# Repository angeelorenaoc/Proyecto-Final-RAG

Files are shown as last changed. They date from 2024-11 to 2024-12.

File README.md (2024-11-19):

# Proyecto-Final-RAG
Este proyecto tiene como objetivo desarrollar un robot guía autónomo para el pasillo del bloque 18 de la universidad. Diseñado para mejorar la experiencia de los estudiantes nuevos y visitantes, el robot proporcionará información útil y rutas. Él estará equipado con una pantalla OLED y un teclado, facilitando la interacción con los usuarios.

### Diagrama de Bloques: Estructura de Hardware

WhatsApp Image 2024-11-12 at 9 45 18 PM

### Materiales 
  *  Pantalla OLED.
  *  Balizas: Antenas XBEE PRO.
  *  Raspberry Pi pico

### Diagrama de Flujo: Estructura del Código
WhatsApp Image 2024-11-04 at 5 30 25 AM

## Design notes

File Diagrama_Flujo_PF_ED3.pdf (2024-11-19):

Diagrama de máquinas de estado del Programa Principal

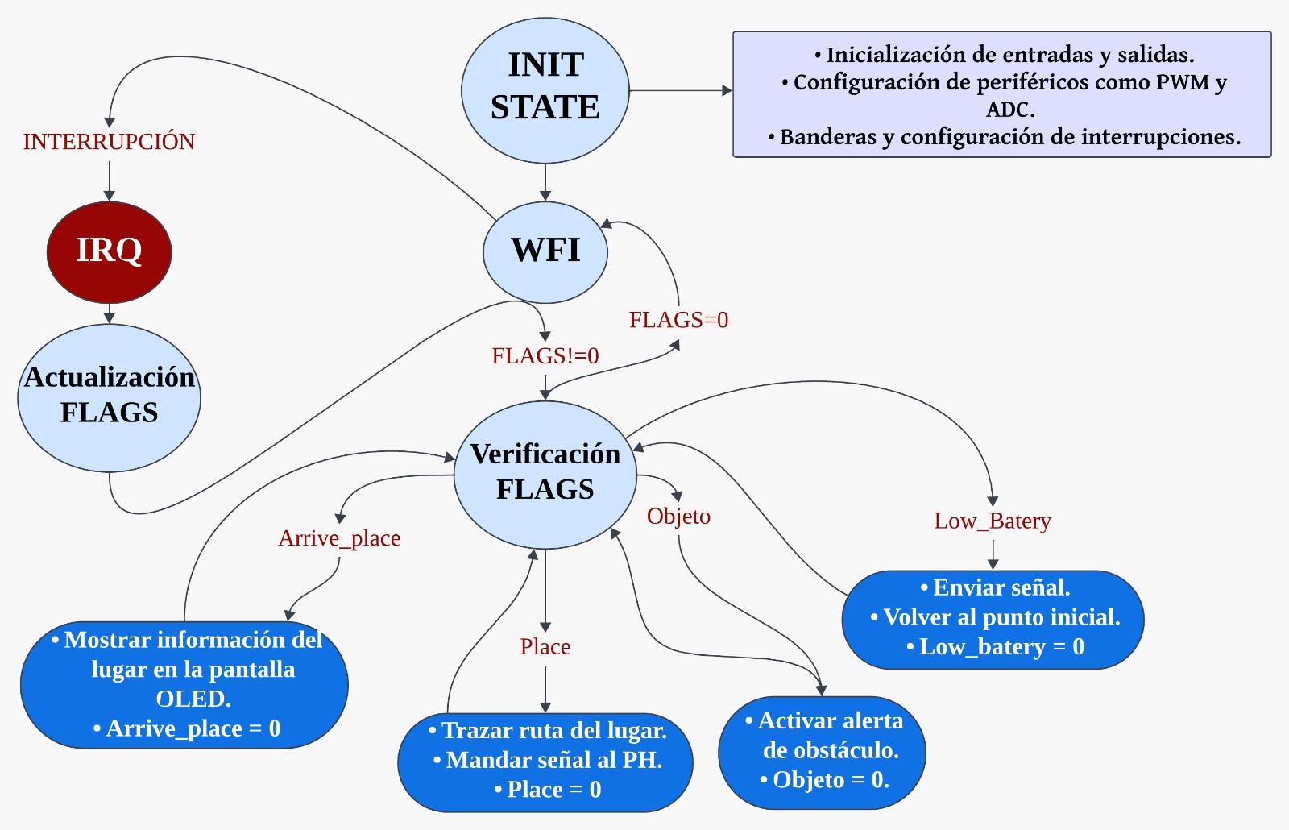
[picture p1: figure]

En primera instancia se optó por un flujo de tipo Polling + Interrup Driven ya que nos permite tener un buen control de los eventos sin necesidad de estar en un estado de constante atención por parte del procesador lo que ayuda también al consumo energético de sistema; El programa parte por la inicialización de todas las variables y GPIOs necesarios como también de los distintos periféricos (PWM, ADC, UART, I2C) para interconectar el MCU con el mundo exterior. Seguidamente activa todas las interrupciones requeridas que modificaran las respectivas flags dependiendo del evento que se les asigne, algunas generadas por medio de alarmas o PITs , o por interrupciones procedentes de los botones conectados.
Ya entrando en el bucle principal la CPU esperara a la ocurrencia de algún evento que modifique las flags y estas a su vez indiquen que procedimiento realizar:
- Refresco de la pantalla OLED a través de la interfaz I2C
- Generación del PWM para el movimiento
- Detección de obstáculos.
- Actualización de la posición relativa, esto incluye la lectura del nivel de potencia de cada una de las balizas
- Lectura del nivel de batería actual

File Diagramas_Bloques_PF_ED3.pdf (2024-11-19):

Diagrama de Bloques de HW

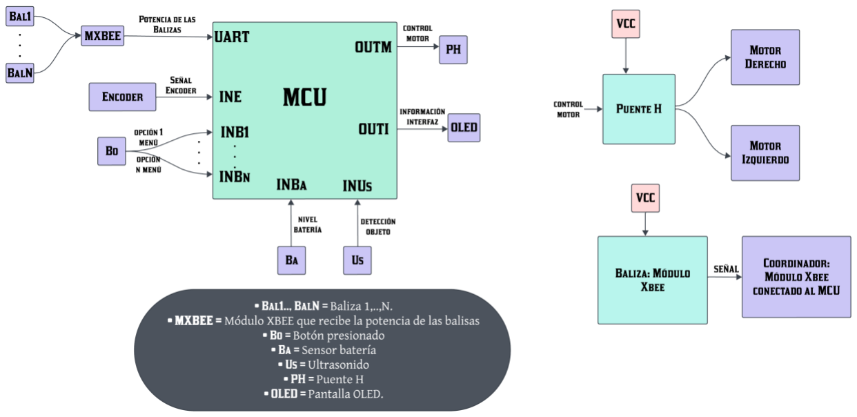
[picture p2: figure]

El gráfico representa el HW del sistema a implementar. Por un lado, se tiene la potencia de las balizas captada por el módulo XBee, que envía los datos recibidos mediante el protocolo de comunicación UART a través de uno de los pines del GPIO, con el propósito de que el robot determine su ubicación con ayuda de un algoritmo de triangulación; asimismo, el MCU recibe los datos proporcionados por los botones para el manejo de la interfaz y por consiguiente el tipo de información mostrada en la pantalla OLED, una vez procesadas las opciones del menú; también, recibirá los datos generados por el encoder con el fin de aumentar la precisión de su movimiento. Otras entradas como el nivel de batería serán estimados mediante un circuito comparador que establezca si el nivel de voltaje se encuentra por debajo de un umbral, puesto que, dado el caso de que su batería llegue a niveles bajos, este deberá volver a su posición inicial. Finalmente, el sensor de ultrasonido influirá a la hora de establecer la dirección a seguir, ya que será el encargado de indicar la presencia de un objeto, evitando encontrarse en medio del camino de transeúntes.

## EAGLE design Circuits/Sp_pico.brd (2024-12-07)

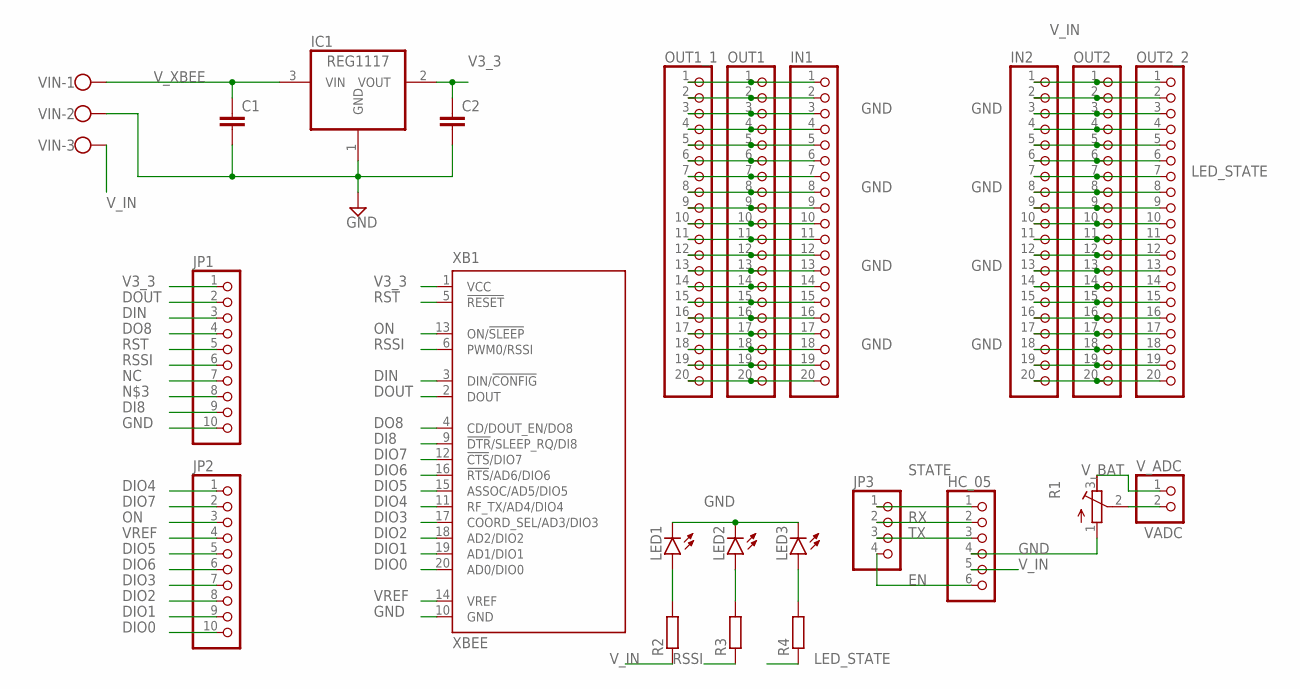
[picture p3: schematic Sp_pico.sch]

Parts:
C1, C2: C2.5/5; C2.5-5
HC_05: PINHD-1X6; 1X06
IC1: REG1117; SOT223
IN1, IN2: PINHD-1X20; 1X20
JP1, JP2: PINHD-1X10; 1X10
JP3: PINHD-1X4; 1X04
LED1, LED2, LED3: LED5MM
OUT1, OUT1_1, OUT2, OUT2_2: PINHD-1X20; 1X20
R1: R-TRIMM3296X; RTRIM3296X
R2, R3, R4: R-EU_0204/7; 0204/7
VIN: W237-103
V_ADC: PINHD-1X2; 1X02
XB1: XBEE

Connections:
DI8: JP1.9, XB1.9 (!DTR!/SLEEP_RQ/DI8)
DIN: JP1.3, XB1.3 (DIN/!CONFIG)
DIO0: JP2.10, XB1.20 (AD0/DIO0)
DIO1: JP2.9, XB1.19 (AD1/DIO1)
DIO2: JP2.8, XB1.18 (AD2/DIO2)
DIO3: JP2.7, XB1.17 (COORD_SEL/AD3/DIO3)
DIO4: JP2.1, XB1.11 (RF_TX/AD4/DIO4)
DIO5: JP2.5, XB1.15 (ASSOC/AD5/DIO5)
DIO6: JP2.6, XB1.16 (!RTS!/AD6/DIO6)
DIO7: JP2.2, XB1.12 (!CTS!/DIO7)
DO8: JP1.4, XB1.4 (CD/DOUT_EN/DO8)
DOUT: JP1.2, XB1.2 (DOUT)
EN: HC_05.6, JP3.4
GND: C1.2, C2.2, HC_05.4, IC1.1 (GND), IN1.3, IN1.8, IN1.13, IN1.18, IN2.3, IN2.8, IN2.13, IN2.18, JP1.10, LED1.K (C), LED2.K (C), LED3.K (C), OUT1.3, OUT1.8, OUT1.13, OUT1.18, OUT1_1.3, OUT1_1.8, OUT1_1.13, OUT1_1.18, OUT2.3, OUT2.8, OUT2.13, OUT2.18, OUT2_2.3, OUT2_2.8, OUT2_2.13, OUT2_2.18, R1.1 (A), VIN.2, XB1.10 (GND)
LED_STATE: IN2.7, OUT2.7, OUT2_2.7, R4.1
unnamed: IN1.1, OUT1.1, OUT1_1.1
unnamed: IN1.2, OUT1.2, OUT1_1.2
unnamed: IN1.4, OUT1.4, OUT1_1.4
unnamed: IN1.5, OUT1.5, OUT1_1.5
unnamed: IN1.6, OUT1.6, OUT1_1.6
unnamed: IN1.7, OUT1.7, OUT1_1.7
unnamed: LED1.A, R2.2
unnamed: IN1.9, OUT1.9, OUT1_1.9
unnamed: IN1.10, OUT1.10, OUT1_1.10
unnamed: IN1.11, OUT1.11, OUT1_1.11
unnamed: IN1.12, OUT1.12, OUT1_1.12
unnamed: LED2.A, R3.2
unnamed: IN1.14, OUT1.14, OUT1_1.14
unnamed: IN1.15, OUT1.15, OUT1_1.15
unnamed: IN1.16, OUT1.16, OUT1_1.16
unnamed: IN1.17, OUT1.17, OUT1_1.17
unnamed: LED3.A, R4.2
unnamed: IN1.19, OUT1.19, OUT1_1.19
unnamed: IN1.20, OUT1.20, OUT1_1.20
unnamed: IN2.2, OUT2.2, OUT2_2.2
unnamed: IN2.4, OUT2.4, OUT2_2.4
unnamed: IN2.5, OUT2.5, OUT2_2.5
unnamed: IN2.6, OUT2.6, OUT2_2.6
unnamed: IN2.9, OUT2.9, OUT2_2.9
unnamed: IN2.10, OUT2.10, OUT2_2.10
unnamed: IN2.11, OUT2.11, OUT2_2.11
unnamed: IN2.12, OUT2.12, OUT2_2.12
unnamed: IN2.14, OUT2.14, OUT2_2.14
unnamed: IN2.15, OUT2.15, OUT2_2.15
unnamed: IN2.16, OUT2.16, OUT2_2.16
unnamed: IN2.17, OUT2.17, OUT2_2.17
unnamed: IN2.19, OUT2.19, OUT2_2.19
unnamed: IN2.20, OUT2.20, OUT2_2.20
NC: JP1.7
ON: JP2.3, XB1.13 (ON/!SLEEP)
RSSI: JP1.6, R3.1, XB1.6 (PWM0/RSSI)
RST: JP1.5, XB1.5 (!RESET)
RX: HC_05.2, JP3.2
STATE: HC_05.1, JP3.1
TX: HC_05.3, JP3.3
V3_3: C2.1, IC1.2 (VOUT), JP1.1, XB1.1 (VCC)
VADC: R1.2 (S), V_ADC.2
VREF: JP2.4, XB1.14 (VREF)
V_BAT: R1.3 (E), V_ADC.1
V_IN: HC_05.5, IN2.1, OUT2.1, OUT2_2.1, R2.1, VIN.3
V_XBEE: C1.1, IC1.3 (VIN), VIN.1

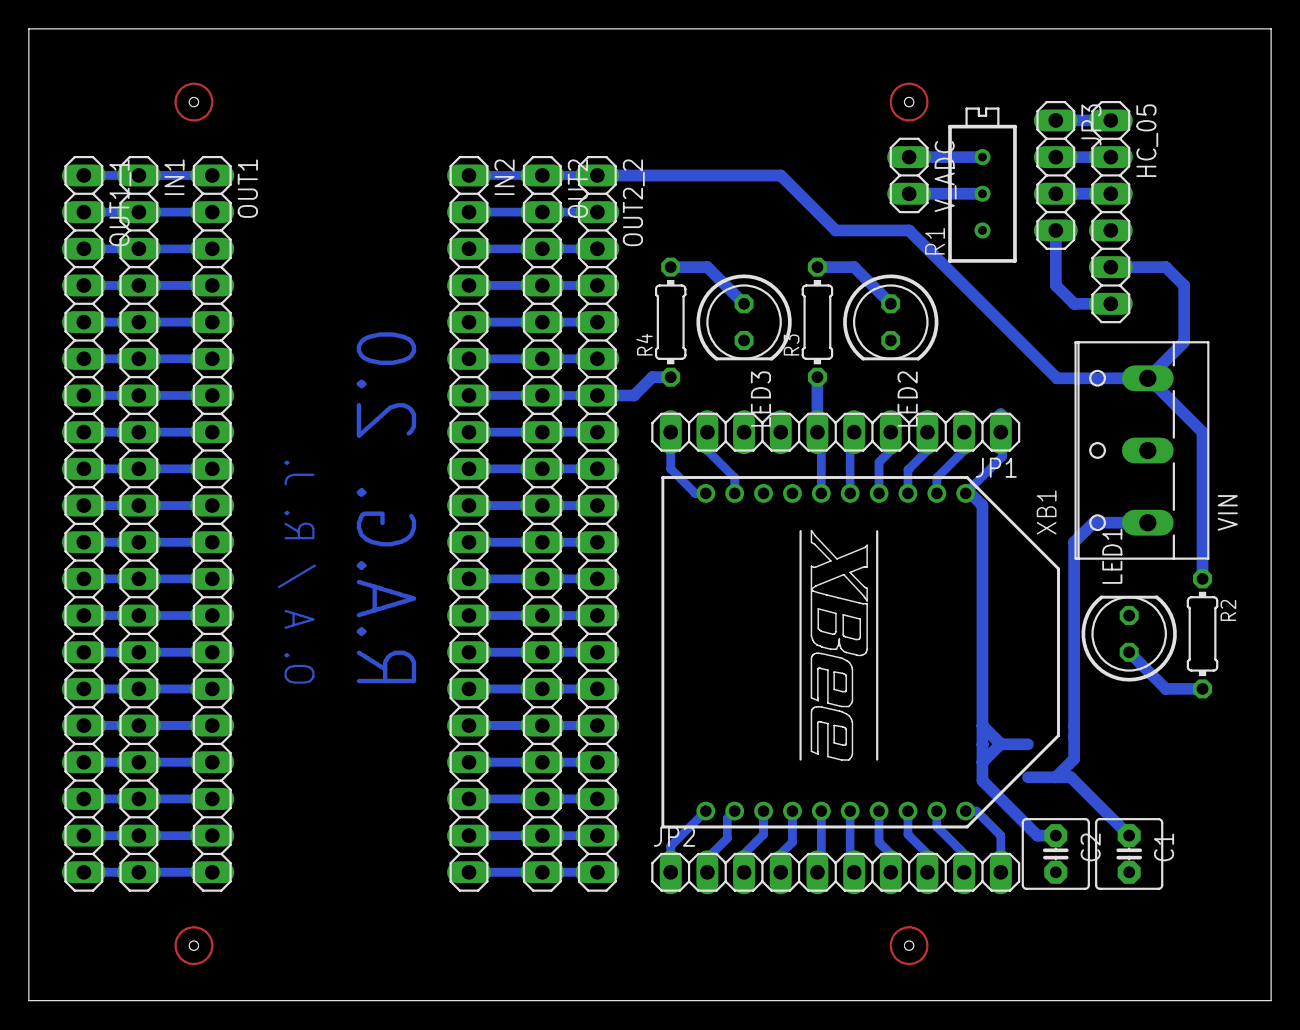
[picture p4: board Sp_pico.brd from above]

Board: 2 copper layers, 86.0 x 67.3 mm, 23 parts (1 on the bottom side), 60 nets.

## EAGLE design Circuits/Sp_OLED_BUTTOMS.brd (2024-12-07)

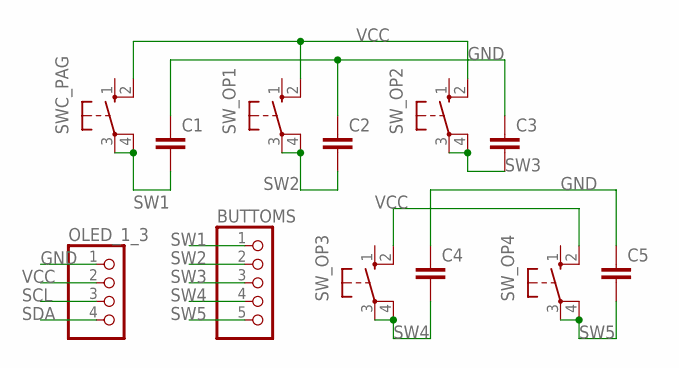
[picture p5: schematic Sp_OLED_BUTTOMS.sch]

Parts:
BUTTOMS: PINHD-1X5; 1X05
C1, C2, C3, C4, C5: C2,5-3; C2.5-3
OLED_1_3: PINHD-1X4; 1X04
SWC_PAG: 10-XX; B3F-10XX
SW_OP1, SW_OP2, SW_OP3, SW_OP4: 10-XX; B3F-10XX

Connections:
GND: C1.1, C2.1, C3.1, C4.1, C5.1, OLED_1_3.1
SCL: OLED_1_3.3
SDA: OLED_1_3.4
SW1: BUTTOMS.1, C1.2, SWC_PAG.3, SWC_PAG.4 (P1)
SW2: BUTTOMS.2, C2.2, SW_OP1.3, SW_OP1.4 (P1)
SW3: BUTTOMS.3, C3.2, SW_OP2.3, SW_OP2.4 (P1)
SW4: BUTTOMS.4, C4.2, SW_OP3.3, SW_OP3.4 (P1)
SW5: BUTTOMS.5, C5.2, SW_OP4.3, SW_OP4.4 (P1)
VCC: OLED_1_3.2, SWC_PAG.2 (S1), SW_OP1.2 (S1), SW_OP2.2 (S1), SW_OP3.2 (S1), SW_OP4.2 (S1)

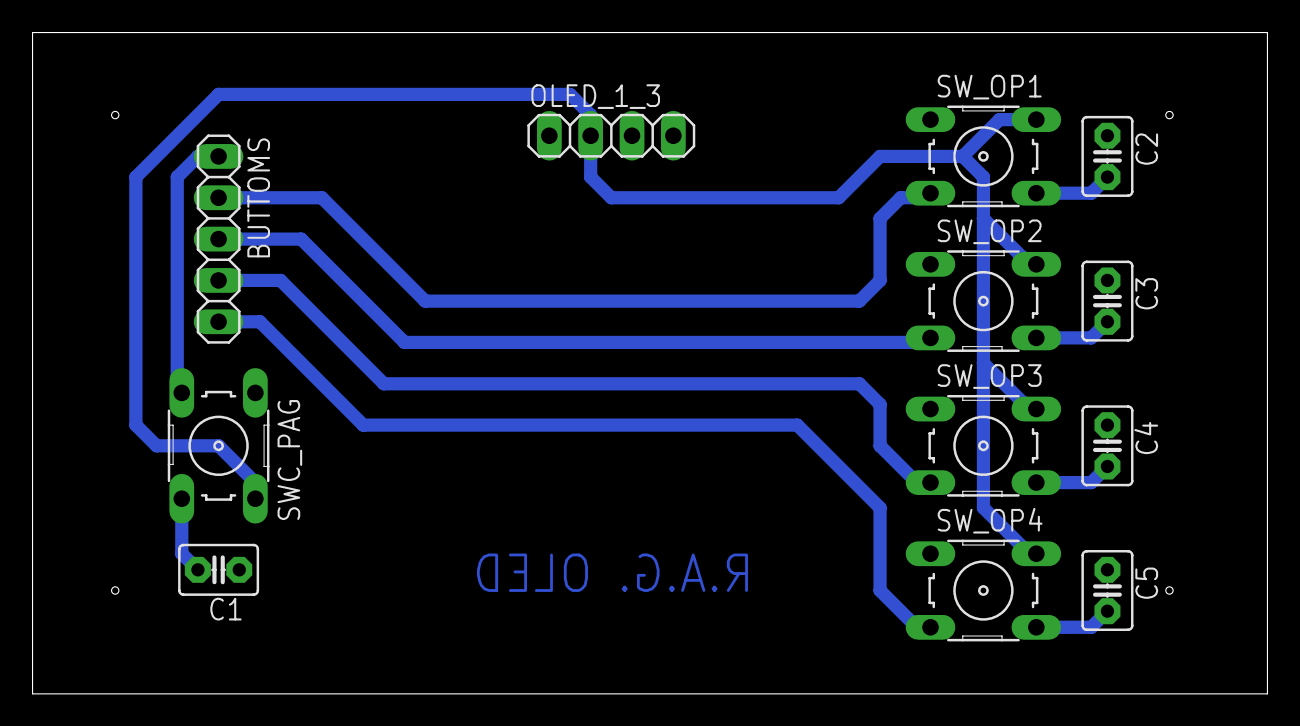
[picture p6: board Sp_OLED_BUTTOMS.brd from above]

Board: 2 copper layers, 75.9 x 40.6 mm, 12 parts (0 on the bottom side), 7 nets.

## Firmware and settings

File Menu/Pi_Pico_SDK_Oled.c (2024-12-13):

#include "main.h"
/*FALTA PROBAR*/
absolute_time_t now, target, now1, target1, now_w, target_w;
const uint alarm_text = 0;
const uint alarm_menu = 1;
const uint alarm_antena = 2;
uint8_t count_page = 0;
volatile uint32_t gpio_interrup, mask_interrup;

uint32_t slice_num = 0 ;
uint32_t dutymask = 0;

/* Fin de carrera*/
uint32_t gpio_final_carrera = 0xf;
uint32_t init_time, delta_time;

/*LINEA*/
const uint32_t mask_motor = 0xF << 10;
const uint32_t gpio_linea = 0x3 << 6;
const uint32_t gpio_boton = 0x1F << 18;
bool band_right = false;
bool band_left = false; 
uint8_t verificacion = 0, pos_cand = 0; //Posición candidata para la triangulación 
uint sliceNumMotorA = 0, sliceNumMotorB = 0;

bt_data_t Datos;

volatile uint32_t gpios;
/*--------------------- ISR RAG --------------------------*/
void alarm_duty(uint alarm){
    // Calcula el duty de la seañl cada 10ms
    measure_duty_cycle(slice_num,&Balizas[Baliza-1].WORD);
    Flags.BITS.Capture_ADC = 0;
    ////printf("CAPTURANDO RSSI: %d, CR: %d\n", Balizas[Baliza-1].BITS.RSSI, CR);
}


/*--------------------------- ISR MENU ---------------------------*/

void gpio_isr(uint gpio, uint32_t mask_event){//Antirrebote
  gpios = gpio_get_all()&(3<<6|0xf);
  ////printf("Entra a la IRQ, gpio: %x \n", gpio);
  switch (gpios){
    case 1://Fin de carrera 1
      if(gpio_get(gpio)){
        menu.BITS.choque = 1;
      }
      else{
        menu.BITS.choque = 0;
      }
    break;
    case 2://Fin de carrera 2
      if(gpio_get(gpio)){
      menu.BITS.choque = 1;
      }
      else{
        menu.BITS.choque = 0;
      }

    break;
    case 4://Fin de carrera 3
      if(gpio_get(gpio)){
      menu.BITS.choque = 1;
      }
      else{
        menu.BITS.choque = 0;
      }
    break;
    case 8://Fin de carrera 4
      if(gpio_get(gpio)){
      menu.BITS.choque = 1;
      }
      else{
        menu.BITS.choque = 0;
      }
    break; 
    case (1<<6):
        ////printf("IZQUIERDA ..............\n");
        band_left = true;
        break;
    case (1<<7):
        ////printf("DERECHA ..............\n");
        band_right = true;
        break;    
    default://Botones del menú
      ////printf("Desahabilita la interrupcion............... \n");
      now = get_absolute_time();
      target = delayed_by_ms(now, TIME_DEBOUNCE);
      hardware_alarm_set_target(alarm_menu, target);
      gpio_set_irq_enabled(18, GPIO_IRQ_EDGE_RISE, false);
      gpio_set_irq_enabled(19, GPIO_IRQ_EDGE_RISE, false);
      gpio_set_irq_enabled(20, GPIO_IRQ_EDGE_RISE, false);
      gpio_set_irq_enabled(21, GPIO_IRQ_EDGE_RISE, false);
      gpio_set_irq_enabled(22, GPIO_IRQ_EDGE_RISE, false);
      break;
  }
  //mask_interrup = mask_event;
  //gpio_interrup = gpio;
  gpio_acknowledge_irq(gpio_interrup,mask_interrup);
  ////printf("---------------------- start alarm -------------------\n");
}

void delay_show(uint alarm){//Tiempo para el cambio de página
  if((menu.BITS.Show_Info2 && count_page < 4) || (menu.BITS.End && count_page < 5))
  {
    //printf("------Alarma del texto ----\n");
    //printf("pag: %d\n",count_page);
    Flags1.BITS.CONFIG_ALARM = 1;
  } 
  else{
    count_page=0;
  }

}

void eleccion(uint alarm1){//Botones
  gpios = (gpio_get_all()>>18) & 0x1f;
  //printf("Entra a la interrupcion, gpio: %x \ngpios: %x\nmenu: %x\n", gpio_interrup,gpios, menu.WORD);
    switch (gpios)
    {
    case 1: //Rojo
      switch (menu.WORD) //Opciones de pagina
      {
      case 1: //Pasar al menú de opciones
        menu.BITS.Menu1 = 1;
        menu.BITS.Reset = 0;
        break;
      case 2: //Devolverse al estado de Reset
        menu.BITS.Reset = 1;
        menu.BITS.Menu1 = 0;
        break;
      case 16: //Ir a la despedida
        menu.BITS.End = 1;
        menu.BITS.Show_Info2 = 0;
        Flags1.BITS.CONFIG_ALARM = 1;
        count_page = 0;
        break;
      case 8: //Volver al estado de reset
        menu.BITS.Reset = 1;
        menu.BITS.End = 0;
        break; 

      default:
        break;
      }
      break;

    case 2: //Opción 1
      menu.BITS.Menu1 = 0;
      menu.BITS.Triangular = 1;
      opcion.WORD = 0;
      opcion.BITS.LED = 1;
      Flags.BITS.Reset = 1;
      oledWriteString(&oled, 0,0,0,(char *)"Moviendome",FONT_8x8,0,1);
      gpio_set_irq_enabled(6, GPIO_IRQ_EDGE_RISE|GPIO_IRQ_EDGE_FALL, true);
      gpio_set_irq_enabled(7, GPIO_IRQ_EDGE_RISE|GPIO_IRQ_EDGE_FALL, true);
      pos_obj = '0';
      break;

    case 4: //Opción 2
      menu.BITS.Menu1 = 0;
      menu.BITS.Triangular = 1;
      opcion.WORD = 0;
      opcion.BITS.GITA = 1;
      Flags.BITS.Reset = 1;
      oledWriteString(&oled, 0,0,0,(char *)"Moviendome",FONT_8x8,0,1);
      gpio_set_irq_enabled(6, GPIO_IRQ_EDGE_RISE|GPIO_IRQ_EDGE_FALL, true);
      gpio_set_irq_enabled(7, GPIO_IRQ_EDGE_RISE|GPIO_IRQ_EDGE_FALL, true);
      pos_obj = '1';
      break;

    case 8: //Opción 3
      menu.BITS.Menu1 = 0;
      menu.BITS.Triangular = 1;
      opcion.WORD = 0;
      opcion.BITS.LEB = 1;
      Flags.BITS.Reset = 1;
      oledWriteString(&oled, 0,0,0,(char *)"Moviendome",FONT_8x8,0,1);
      gpio_set_irq_enabled(6, GPIO_IRQ_EDGE_RISE|GPIO_IRQ_EDGE_FALL, true);
      gpio_set_irq_enabled(7, GPIO_IRQ_EDGE_RISE|GPIO_IRQ_EDGE_FALL, true);
      pos_obj = '2';
      break;

    case 16: //Opción 4
      menu.BITS.Menu1 = 0;
      menu.BITS.Triangular = 1;
      opcion.WORD = 0;
      opcion.BITS.LTS = 1;
      Flags.BITS.Reset = 1;
      oledWriteString(&oled, 0,0,0,(char *)"Moviendome",FONT_8x8,0,1);
      gpio_set_irq_enabled(6, GPIO_IRQ_EDGE_RISE|GPIO_IRQ_EDGE_FALL, true);
      gpio_set_irq_enabled(7, GPIO_IRQ_EDGE_RISE|GPIO_IRQ_EDGE_FALL, true);
      pos_obj = '3';
      break;

    default:
      break;
    }
    if(gpios&0x1e){
        gpio_set_irq_enabled(19, GPIO_IRQ_EDGE_RISE, false);
        gpio_set_irq_enabled(20, GPIO_IRQ_EDGE_RISE, false);
        gpio_set_irq_enabled(21, GPIO_IRQ_EDGE_RISE, false);
        gpio_set_irq_enabled(22, GPIO_IRQ_EDGE_RISE, false);
    }
    gpio_set_irq_enabled(18, GPIO_IRQ_EDGE_RISE, true);
}

int main() {
  stdio_init_all();
  sleep_ms(4000);

  /*---------------------- Configuración de los pines ----------------------*/
  gpio_init_mask(mask_motor | (1<<PIN_PWM_ENABLE) | (1<<MEASURE_PIN) | gpio_final_carrera | gpio_linea | gpio_boton);

  gpio_set_dir_out_masked(mask_motor| (1<<PIN_PWM_ENABLE) | (1<<MEASURE_PIN));

  gpio_pull_down(0);
  gpio_pull_down(1);
  gpio_pull_down(2);
  gpio_pull_down(3);
  gpio_pull_down(18);
  gpio_pull_down(19);
  gpio_pull_down(20);
  gpio_pull_down(21);
  gpio_pull_down(22);

  gpio_set_input_hysteresis_enabled(0, true);
  gpio_set_input_hysteresis_enabled(1, true);
  gpio_set_input_hysteresis_enabled(2, true);
  gpio_set_input_hysteresis_enabled(3, true);
  gpio_set_input_hysteresis_enabled(18,true);
  gpio_set_input_hysteresis_enabled(19,true);
  gpio_set_input_hysteresis_enabled(20,true);
  gpio_set_input_hysteresis_enabled(21,true);
  gpio_set_input_hysteresis_enabled(22,true);

  /*-------------------------------------- FINAL DE CARRERA --------------------------------------*/
  gpio_set_irq_enabled_with_callback(0, GPIO_IRQ_EDGE_RISE|GPIO_IRQ_EDGE_FALL, false, &gpio_isr);
  gpio_set_irq_enabled_with_callback(1, GPIO_IRQ_EDGE_RISE|GPIO_IRQ_EDGE_FALL, false, &gpio_isr);
  gpio_set_irq_enabled_with_callback(2, GPIO_IRQ_EDGE_RISE|GPIO_IRQ_EDGE_FALL, false, &gpio_isr);
  gpio_set_irq_enabled_with_callback(3, GPIO_IRQ_EDGE_RISE|GPIO_IRQ_EDGE_FALL, false, &gpio_isr);

  /*-------------------------------------- SENSOR DE LINEA --------------------------------------*/
  gpio_set_irq_enabled_with_callback(6, GPIO_IRQ_EDGE_RISE|GPIO_IRQ_EDGE_FALL, false, &gpio_isr);
  gpio_set_irq_enabled_with_callback(7, GPIO_IRQ_EDGE_RISE|GPIO_IRQ_EDGE_FALL, false, &gpio_isr);

  /*-------------------------------------- BOTONES --------------------------------------*/
  gpio_set_irq_enabled_with_callback(18, GPIO_IRQ_EDGE_RISE, false, &gpio_isr);
  gpio_set_irq_enabled_with_callback(19, GPIO_IRQ_EDGE_RISE, false, &gpio_isr);
  gpio_set_irq_enabled_with_callback(20, GPIO_IRQ_EDGE_RISE, false, &gpio_isr);
  gpio_set_irq_enabled_with_callback(21, GPIO_IRQ_EDGE_RISE, false, &gpio_isr);
  gpio_set_irq_enabled_with_callback(22, GPIO_IRQ_EDGE_RISE, false, &gpio_isr);

  /*------------------ Configuración de las alarmas ------------------ */

  hardware_alarm_claim(alarm_menu);
  hardware_alarm_set_callback(alarm_menu, &eleccion);
  hardware_alarm_claim(alarm_text);
  hardware_alarm_set_callback(alarm_text, &delay_show);

  //------------------------------------ UART ------------------------------------ 
  uart_init(UART_ID, BAUD_RATE);
  gpio_set_function(UART_TX_PIN, UART_FUNCSEL_NUM(UART_ID, UART_TX_PIN));
  gpio_set_function(UART_RX_PIN, UART_FUNCSEL_NUM(UART_ID, UART_RX_PIN));
  gpio_set_function(MEASURE_PIN, GPIO_FUNC_PWM);
  int __unused actual = uart_set_baudrate(UART_ID, BAUD_RATE);
  uart_set_hw_flow(UART_ID, false, false);
  uart_set_format(UART_ID, DATA_BITS, STOP_BITS, PARITY);
  uart_set_fifo_enabled(UART_ID, true);
  int UART_IRQ = UART_ID == uart0 ? UART0_IRQ : UART1_IRQ;
  irq_set_exclusive_handler(UART_IRQ, Capture);
  irq_set_enabled(UART_IRQ, true);
  uart_set_irq_enables(UART_ID, true, false);

  /*-------------------- Inicialización de PWMs -------------------- */
  cfg1 = pwm_get_default_config();
  pwm_config_set_clkdiv_mode(&cfg1, PWM_DIV_B_HIGH);
  pwm_config_set_clkdiv(&cfg1, 50);

  /*------------- Configuración del enable de los motores --------------*/
  gpio_set_function(PIN_PWM_ENABLEA, GPIO_FUNC_PWM);
  sliceNumMotorA = pwm_gpio_to_slice_num(PIN_PWM_ENABLEA);
  pwm_set_clkdiv_int_frac(sliceNumMotorA, PWM_DIV_INTEGER, PWM_DIV_FRAC); 
  pwm_set_wrap(sliceNumMotorA, PWM_TOP_VALUE);
  pwm_set_chan_level(sliceNumMotorA, PWM_CHA, PWM_DUTY_ZERO);
  pwm_set_enabled(sliceNumMotorA, true); 
  
  gpio_set_function(PIN_PWM_ENABLEB, GPIO_FUNC_PWM);
  sliceNumMotorB = pwm_gpio_to_slice_num(PIN_PWM_ENABLEB);
  pwm_set_clkdiv_int_frac(sliceNumMotorB, PWM_DIV_INTEGER, PWM_DIV_FRAC);
  pwm_set_wrap(sliceNumMotorB, PWM_TOP_VALUE);
  pwm_set_chan_level(sliceNumMotorB, PWM_CHA, PWM_DUTY_ZERO);
  pwm_set_enabled(sliceNumMotorB, true); 

  //Inicia en el estado de Reset
  Flags.WORD = 0;
  menu.WORD = 1;
  slice_num = pwm_gpio_to_slice_num(MEASURE_PIN);


  /*---------- Configuración de la alarma ---------------*/
  if(hardware_alarm_is_claimed(alarm_antena)){
    //printf("NO ES POSIBLE USAR ESTA ALARMA \n");
  }
  else{
    hardware_alarm_claim(alarm_antena);
    hardware_alarm_set_callback(alarm_antena, &alarm_duty);
    ////printf("Configurar alarma antena \n");
  }
  /* ---------- Configuración del ADC ---------- */
   adc_init();
    adc_gpio_init(ADC_MEASURE_PIN);
    adc_select_input(0);

  /*------------------------ Pantalla ------------------------*/  
  char szTemp[32];
  rc = oledInit(&oled, OLED_128x64, 0x3c, 0, 0, 1, SDA_PIN, SCL_PIN, RESET_PIN, 1000000L);
  
  /*-------------- Inicialización del Bluetooth --------------*/  
  bt_init();
  bt_set_data(&Datos);

  /*-------------- Inicialización de los datos --------------*/ 
  Datos.n_bat = adc_read();
  Datos.bl_rssi[0] = 000; 
  Datos.bl_rssi[1] = 000;
  Datos.bl_rssi[2] = 000; 
  Datos.bl_rssi[3] = 000;  
  Datos.sw[0] = 0;
  Datos.sw[1] = 0;
  Datos.sw[2] = 0;
  Datos.sw[3] = 0;

  bool check = bt_get_hour();// Obtiene la hora y la configura
  if (check)
  {
    bt_transmit_ok();
  }
  else{
    bt_transmit_nok();
  }
  bt_transmit_alarm();

  while (1)
  { 
    switch (menu.WORD)
    {
    case 1:
      /*------------------------------------ INICIO ------------------------------------*/
      gpio_set_irq_enabled_with_callback(18, GPIO_IRQ_EDGE_RISE, true, &gpio_isr);
      initUHD(&oled, &menu, 0);
      opcion.WORD = 0;
      Flags.BITS.Reset=0;
      break;    
    case 2:
      /* -------------------------- Menu lugares -------------------------- */     
      gpio_set_irq_enabled(19, GPIO_IRQ_EDGE_RISE, true);
      gpio_set_irq_enabled(20, GPIO_IRQ_EDGE_RISE, true);
      gpio_set_irq_enabled(21, GPIO_IRQ_EDGE_RISE, true);
      gpio_set_irq_enabled(22, GPIO_IRQ_EDGE_RISE, true);
      //Mostrar el menu
      Menu1(&oled);
      Flags.BITS.Reset=0;
      break;
    case 4:
      switch (Flags.WORD){
        /*----------------------------------- TRIANGULACIÓN -----------------------------------*/
        case 1:
            Reset();
            uart_puts(UART_ID, str);
            break;
        case 12:
            //Pasar a .h
            pwm_init(slice_num, &cfg1, false);
            //CONFIGURACIÓN ALARMA 10MS
            now = get_absolute_time();
            target = delayed_by_ms(now, COUNT_MEASURE_TIME);
            hardware_alarm_set_target(alarm_antena, target);
            pwm_set_enabled(slice_num, true);
            break;
        case 0x10:
            Fin_Trama();
            Triangulación();
            Move();      
            actu_data();
            break;
        default:
            break;
      }
      if (!Flags.BITS.Reset || !Flags.BITS.OK)
      {
        Move(); 
      }
      
      //Info del lugar
      if(Flags.BITS.Llego){
        menu.BITS.Show_Info2 = 1;
        menu.BITS.Triangular = 0; 
      }

      break;

    case 0x24: //Choque de objeto
      initUHD(&oled, &menu, 0);
      actu_data();
      Move();
    break;

    case 16:
          Info_Place(&opcion);
          if(count_page>3)
          {
            opcion.WORD = 0;
          }
          
    break;
    case 8:
      /* ------------------- Final del recorrido ------------------- */
      Despedida(&oled, count_page);
      Flags.BITS.Llego = 0;
      break;

    default:
      menu.WORD = 1;
      break;
    }
    if (Flags1.BITS.CONFIG_ALARM)
    {
      now1 = get_absolute_time();
      if(menu.BITS.Show_Info2){
        
        target1 = delayed_by_ms(now1, TIME_TEXT);
        hardware_alarm_set_target(alarm_text, target1);
      }
      else if (menu.BITS.End)
      {
        if(count_page == 1){
          target1 = delayed_by_ms(now1, TIME_TEXT);
        }
        else{
          target1 = delayed_by_ms(now1, TIME_FIN);
        }
        hardware_alarm_set_target(alarm_text, target1);
      }
      Flags1.BITS.CONFIG_ALARM = 0;
      count_page++;
    }
    if(!Flags.BITS.Reset){
         __wfi();
    }
  }

  return 0;
}

void Capture(){
  /*
  \brief Captura la trama recibida por la antena
  */
    char c = uart_getc(UART_ID);
    switch (Flags.WORD & (0x3<<1))
    {
    case 2:
        // Recepción de OK
        BOK[count] = c;
        break;

    case 4:
        // Recibiendo trama de cada una de las balizas
        if(c != 0x0D && CR%10 == 3){
            // Captura y almacena el ID de la baliza
            Balizas[Baliza].BITS.NI = c;
            Baliza++;
        }
        if(c == 0x0D){
            if(CR == N_CRpb){
                //Indica Gin de trama
                Flags.BITS.EndMsg = 1;
                Flags.BITS.Capture = 0;
            }
            CR++;            
        }
        break;
    default:
        break;
    }
    if(count == N_OK && Flags.BITS.OK){
        //Final del OK recibido

        Flags.BITS.Capture = 1;
        Flags.BITS.OK = 0;
        count = 0;
        uart_puts(UART_ID, at_comand);
    }
    if(CR%10 == 6  && Flags.BITS.Capture){
        // Habilita el calculo del duty del duty 
        Flags.BITS.Capture_ADC = 1;
    }
    count++;////printf("\n");
}

inline void Triangulación(){
  /*
  \brief Actualiza la posición en la cual se encuentra de acuerdo a la potencia almacenada para cada una de las balizas 
  */
    for (uint8_t i = 0; i < sizeof(UB); i++)
    {
      if((Balizas[i].BITS.RSSI) > Umbral){
        if(Balizas[i].BITS.NI>47){//47 se refiere al char
          if(Balizas[i].BITS.NI == pos_cand){
            pos_act = pos_cand; 
          }
          else{
            pos_cand = Balizas[i].BITS.NI;
          }
        }   
      }        
    }    
}

inline void Move(){
  /*
  \brief Evalue la posición para definir el movimiento del motor.
  */
    //Pin 10: Enable
    //Pin 11 : Salida A
    //Pin 12 : Salida B
    if (pos_act != 0)
    {
      if (pos_act > pos_obj)
      {
          gpio_put_masked(mask_motor & (0x5 << 11), mask_motor & (0x1 << 11));
          Flags.BITS.Llego = 0;
          Corregir_atras();
      }
      else if (pos_act < pos_obj)
      {
          gpio_put_masked(mask_motor & (0x5 << 11), mask_motor & (0x1 << 13));
          Flags.BITS.Llego = 0;
          Corregir_adelante();
          
      }
      else{
          gpio_put_masked(mask_motor & (0x5 << 11), 0x0);
          Flags.BITS.Llego = 1;
          Flags1.BITS.CONFIG_ALARM = 1;
          Flags.BITS.Reset = 0;
          gpio_set_irq_enabled(6, GPIO_IRQ_EDGE_RISE | GPIO_IRQ_EDGE_FALL, false);
          gpio_set_irq_enabled(7, GPIO_IRQ_EDGE_RISE | GPIO_IRQ_EDGE_FALL, false);
      } 
      if(menu.BITS.choque){
        gpio_put_masked(mask_motor & (0x5 << 11), 0x0);
      }
    }
    
}


void Reset(){
  /*
  \brief Lleva los valores de variables y banderas a su estado por defecto
   */
    for (uint8_t i = 0; i < N_BALIZAS; i++)
    {
        Balizas[i].WORD = 0; 
    }
    count = 0;
    CR = 0;
    Flags.WORD = 2;
    Baliza = 0;
}

void Fin_Trama(){
  /*
  \brief Permite depurar el contenido de la trtama para la lectura y verificación de los datos
  */
  
    for (uint8_t i = 0; i < N_BALIZAS; i++)
    {
        //printf("El valor de la baliza %d es igual a %d \n", Balizas[i].BITS.NI, Balizas[i].BITS.RSSI);
    }
    Flags.WORD = 1;
}
void Despedida(SSOLED *oled, uint8_t count){
  /*
  \brief Despedida al usuario una vez finaliza el recorrido
  \param oled puntero en el cual se encuentra la estructura de datos para la configuración de la OLED 
  \param count contador que indica el número de página.
  */
  switch (count)
  {
  case 1:
    //printf("Entró");
    oledFill(oled, 0,1);
    oledWriteString(oled, 0,0,1,(char *)"   ESTE ES EL", FONT_8x8, 0,1);
    oledWriteString(oled,0,0,2,(char*)  "    FIN DEL", FONT_8x8, 0,1);
    oledWriteString(oled,0,0,3,(char *) "   RECORRIDO.", FONT_8x8, 0,1);
    oledWriteString(oled,0,0,4,(char *) "    HA SIDO", FONT_8x8, 0,1);
    oledWriteString(oled,0,0,5,(char *) "   UN PLACER", FONT_8x8, 0,1); 
    oledWriteString(oled,0,0,6,(char *) "  ACOMPANARTE" , FONT_8x8, 0,1);
    break;
  case 2: 
    initUHD(oled, &menu, count_page);
    break;
  
  case 3:
    initUHD(oled, &menu, count_page);
    break;

  case 4:
    initUHD(oled, &menu, count_page);
    break;
  
  default:
    break;
  }
}
void Info_Place(opcion_t *op_m1){
  /*
  \brief Manejo de la visualización de la información de cada uno de los lugares de acuerdo a la opción escogida en el menú
  \param op_m1 Puntero a la estructura que contiene la opción escogida en el menú*/
  if (rc != OLED_NOT_FOUND){
    switch (op_m1->WORD)
    {
    case 1:
      Info_LED(&oled, count_page);
      break;

    case 2:
      Info_GITA(&oled, count_page);
    break;

    case 4:
      Info_Basicos(&oled, count_page);
      break;
    
    case 0x8:
      Info_Senales(&oled, count_page);
    break;

    default:
      break;
    }
  }

}
void initUHD(SSOLED *oled, state_menu *menu, uint8_t count){
  /*
  \brief Configuración de las caras mostradas en la pantalla
  \param oled puntero en el cual se encuentra la estructura de datos para la configuración de la OLED 
  \param count contador que indica el número de página.
  \param menu puntero a la estructura que contiene la opción del menú
  */
  oledSetBackBuffer(oled, ucBuffer);
  switch (menu->WORD)
  {
  case 0x1:
    oledDumpBuffer(oled,PicandoOJO);
    break;
  
  case 0x8:
    switch (count)
    {
      case 2:
        oledDumpBuffer(oled,Comenzar_Bostezar);
        break;
      
      case 3:
        oledDumpBuffer(oled,Bostezando);
        break;
      case 4:
        oledDumpBuffer(oled,Durmiendo);
        break;    
      default:
        break;
    }    
    break;
  case 0x24:
      oledDumpBuffer(oled,Mareado);
      break;
  
  default:
    break;
  }
}
void Corregir_adelante(){
  /*
  \brief Corrección de la dirección con base en la señal generada por los sensores de linea
  */
  if(!gpio_get(6) && !gpio_get(7)){
      pwm_set_chan_level(sliceNumMotorB, PWM_CHA, PWM_DUTY_ZERO);
      pwm_set_chan_level(sliceNumMotorA, PWM_CHA, PWM_DUTY_ZERO);
      band_right = false;
      band_left = false;
  }

  else if (band_right)
  {  
      pwm_set_chan_level(sliceNumMotorA, PWM_CHA, PWM_ZERO);
      pwm_set_chan_level(sliceNumMotorB, PWM_CHA, PWM_LEVEL);
      band_right = false;
  }
  else if (band_left)
  {
      pwm_set_chan_level(sliceNumMotorB, PWM_CHA, PWM_ZERO);
      pwm_set_chan_level(sliceNumMotorA, PWM_CHA, PWM_LEVEL);
      band_left = false;
  }
}
void Corregir_atras(){
  if(!gpio_get(6) && !gpio_get(7)){
      ////printf("Va derecho.........\n");
      pwm_set_chan_level(sliceNumMotorB, PWM_CHA, PWM_DUTY_ZERO);
      pwm_set_chan_level(sliceNumMotorA, PWM_CHA, PWM_DUTY_ZERO);
  }

  else if (band_right)
  {    
      ////printf("Corrige derecha................. \n");
      pwm_set_chan_level(sliceNumMotorA, PWM_CHA, PWM_LEVEL);
      pwm_set_chan_level(sliceNumMotorB, PWM_CHA, PWM_ZERO);
      band_right = false;
  }
  else if (band_left)
  {
      ////printf("Corrige izquierda................. \n");
      pwm_set_chan_level(sliceNumMotorB, PWM_CHA, PWM_LEVEL);
      pwm_set_chan_level(sliceNumMotorA, PWM_CHA, PWM_ZERO);

      band_left = false;
  }
}
void actu_data(){
  /*
  \brief Actualización de buffer que envía los datos mediante el módulo bluetooth
  */
  uint32_t values = gpio_get_all();
  Datos.n_bat = adc_read();
  Datos.sw[0] = values&1;
  Datos.sw[1] = values&(1<<1);
  Datos.sw[2] = values&(1<<2);
  Datos.sw[3] = values&(1<<3);
  for(uint8_t i = 0; i<N_BALIZAS; i++){
    Datos.bl_rssi[(Balizas[i].BITS.NI-48)]=Balizas[i].BITS.RSSI;
  }
  Datos.pos_act = pos_act;
  Datos.pos_obj = pos_obj;
}

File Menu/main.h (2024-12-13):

#include "control_BT.h"
#include "menus.h"
#include "PWM_measure.h"
#include "hardware/adc.h"


#ifndef MAIN_H_
#define MAIN_H_
//Pines de pantalla 
#define SDA_PIN 4
#define SCL_PIN 5
#define RESET_PIN -1
#define OLED_WIDTH 128
#define OLED_HEIGHT 64
#define TIME_DEBOUNCE 200
#define TIME_TEXT     7000
#define TIME_FIN     1000

//Medir batería 
#define ADC_MEASURE_PIN 26

//Botones
#define mask_boton 0x1F << 20

int rc;
static uint8_t ucBuffer[1024];
state_menu menu;
opcion_t  opcion;
flags_t   Flags1;

//Pantalla
SSOLED oled;

//PROTOTIPOS
void initUHD(SSOLED *, state_menu *, uint8_t);
void Info_Place(opcion_t *);

/// ---------------- Macros ---------------- ///
#define UART_ID uart1
#define BAUD_RATE 4800
#define UART_TX_PIN 8
#define UART_RX_PIN 9
#define DATA_BITS 8
#define STOP_BITS 1
#define PARITY    UART_PARITY_NONE
//ADC
#define ADC_GPIO_CH0        26
#define ADC_CH0             0
#define ADC_MIN_READVALUE   30
//BALIZAS
#define WATCHDOG_TIME 2000

#define N_BALIZAS 2
#define N_CRpb N_BALIZAS*10
#define N_OK 2

#define MEASURE_PIN 15
#define COUNT_MEASURE_TIME 10

//Motor
#define PIN_PWM_ENABLE 10
#define PWM_CHA             0
#define PWM_DIV_INTEGER     128
#define PWM_DIV_FRAC        0
#define PWM_TOP_VALUE       4095
#define PWM_DUTY_ZERO       1400
#define PWM_ZERO 0
#define PWM_LEVEL 3500
#define PIN_PWM_ENABLEA 12
#define PIN_PWM_ENABLEB 10

#define Umbral 820U

/// ---------------- Variables ---------------- ///
//BUFFERS
char BOK[N_OK];     // Buffer para recibir los OK del comando AT
uint8_t count = 0;  // Contador que indica el número de bytes recibidos mediante el UART.
uint8_t Baliza = 0;
uint8_t CR = 0;


int ctrl_chan = 0;
static int chars_rxed = 0;
uint16_t Signal_Power = 0;
const char str[] = "+++";
const char comand[] = "ATND\r";
const uint8_t at_comand[5] = {0x41, 0x54, 0x4E, 0x44, 0x0D};

//Estructura para las banderas
typedef union{
    uint8_t WORD;
    struct{
        uint8_t Reset:        1;  // Estado de reset1
        uint8_t OK :          1;  // Recibe los OK2
        uint8_t Capture :     1;  //Captura la trama4
        uint8_t Capture_ADC : 1;  //Captura valor del ADC8
        uint8_t EndMsg      : 1;  // Bandera de finalización de trama16
        uint8_t Llego       : 1;  //Indica cuando llega a la pos objetivo
    }BITS;    
}state_flags;

typedef union
{
    uint32_t WORD;
    struct     {
        uint32_t RSSI  : 16; // Valor Pot señal
        uint32_t NI    : 8;  // Identificador
    }BITS;
}data_baliza_t;

data_baliza_t Balizas[N_BALIZAS];
state_flags Flags;

uint32_t RSSI[4]; 

char response[3];

// TRIANGULACIÓN
uint8_t state = 0;
uint8_t pos_act = 0, pos_obj = '1';

char UB[4] = {'0', '1', '2','3'}; //Ubicación de las balizas 

pwm_config cfg1, cfg2;

/// ---------------- Prototipos de funciones ---------------- ///
void Capture();
void Reset();
void Fin_Trama();
void Triangulación();
void Move();
void Corregir_adelante();
void Corregir_atras();
void actu_data();

#endif

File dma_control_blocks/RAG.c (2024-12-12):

#include <stdio.h>
#include "main.h"

uint32_t slice_num = 0 ;
uint32_t dutymask = 0;
uint32_t measured_duty_cycle = 0 ;
absolute_time_t now, target, now_w, target_w;
const uint alarm1 = 1, watchdog_XBEE = 2;
uint32_t mask_motor = 0xF << 10;
const uint32_t gpio_linea = 0x3;
bool band_right = false;
bool band_left = false;
uint32_t pwm_level = 0;
uint32_t pwm_level_right = 3000;
uint32_t pwm_level_left = 3000;
uint sliceNumMotorA = 0, sliceNumMotorB = 0;

void corregir_mov(uint gpio, uint32_t events) {
    printf("El gpio que genera la interrupcion es: %d, y la mascara es: %x \n", gpio, events);
    if(events != GPIO_IRQ_EDGE_FALL){

        switch (gpio)
        {
        case 0:
            printf("IZQUIERDA ..............\n");
            band_left = true;
            break;
        case 1:
            printf("DERECHA ..............\n");
            band_right = true;
            break;    
        default:
            break;
        }
    }
    gpio_acknowledge_irq(gpio, events);
}

void alarm_duty(uint alarm){
    // Calcula el duty de la seañl cada 10ms
    measure_duty_cycle(slice_num,&Balizas[Baliza-1].WORD);
    Flags.BITS.Capture_ADC = 0;
    printf("CAPTURANDO RSSI: %d, CR: %d\n", Balizas[Baliza-1].BITS.RSSI, CR);
}
void watchdog_irq(uint alarm){
    if(!Flags.BITS.Capture){
        now_w = get_absolute_time();
        target_w = delayed_by_ms(now, WATCHDOG_TIME);
        hardware_alarm_set_target(watchdog_XBEE, target_w);
        printf("Reenviando\n");
    }

}

int main() {
#ifndef uart_default
#warning dma/control_blocks example requires a UART
#else
    stdio_init_all();
    sleep_ms(4000);

    gpio_init(MEASURE_PIN);
    gpio_init_mask(mask_motor | (1<<MEASURE_PIN)| gpio_linea);
    gpio_set_dir_out_masked(mask_motor | (1<<MEASURE_PIN)| (1<<RESET_XBEE_PIN));

    gpio_set_irq_enabled_with_callback(0, GPIO_IRQ_EDGE_RISE|GPIO_IRQ_EDGE_FALL, true, &corregir_mov);
    gpio_set_irq_enabled_with_callback(1, GPIO_IRQ_EDGE_RISE|GPIO_IRQ_EDGE_FALL, true, &corregir_mov);

    //------------------------------------ UART------------------------------------ 
    uart_init(UART_ID, BAUD_RATE);

    // Set the TX and RX pins by using the function select on the GPIO
    // Set datasheet for more information on function select
    gpio_set_function(UART_TX_PIN, UART_FUNCSEL_NUM(UART_ID, UART_TX_PIN));
    gpio_set_function(UART_RX_PIN, UART_FUNCSEL_NUM(UART_ID, UART_RX_PIN));

    int __unused actual = uart_set_baudrate(UART_ID, BAUD_RATE);

    // Set UART flow control CTS/RTS, we don't want these, so turn them off
    uart_set_hw_flow(UART_ID, false, false);

    // Set our data format
    uart_set_format(UART_ID, DATA_BITS, STOP_BITS, PARITY);

    uart_set_fifo_enabled(UART_ID, true);
    
    // Select correct interrupt for the UART we are using
    int UART_IRQ = UART_ID == uart0 ? UART0_IRQ : UART1_IRQ;
     // And set up and enable the interrupt handlers
    irq_set_exclusive_handler(UART_IRQ, Capture);
    irq_set_enabled(UART_IRQ, true);

    // Now enable the UART to send interrupts - RX only
    uart_set_irq_enables(UART_ID, true, false);

    //Configuración de las alarmas
    hardware_alarm_claim(alarm1);
    hardware_alarm_set_callback(alarm1, &alarm_duty);

    //Inicialización del PWM
    //init_pwm(&cfg1, &cfg2);
    cfg1 = pwm_get_default_config();
    pwm_config_set_clkdiv_mode(&cfg1, PWM_DIV_B_HIGH);
    pwm_config_set_clkdiv(&cfg1, 50);

    // Enable PWM
    gpio_set_function(PIN_PWM_ENABLEA, GPIO_FUNC_PWM);
    // Determine the PWM slice connected to GPIO: PWM_GPIO_CHA
    sliceNumMotorA = pwm_gpio_to_slice_num(PIN_PWM_ENABLEA);
    // Set period for frequency divisor
    pwm_set_clkdiv_int_frac(sliceNumMotorA, PWM_DIV_INTEGER, PWM_DIV_FRAC); // What frequency enters to the PWM?
    // Set top (wrap) value (Determines the frequency)
    pwm_set_wrap(sliceNumMotorA, PWM_TOP_VALUE);
    // Set zero duty
    pwm_set_chan_level(sliceNumMotorA, PWM_CHA, PWM_DUTY_ZERO);
    // Enable PWM
    pwm_set_enabled(sliceNumMotorA, true); 
    
    //SERVO
    gpio_set_function(PIN_PWM_ENABLEB, GPIO_FUNC_PWM);
    // Determine the PWM slice connected to GPIO: PWM_GPIO_CHA
    sliceNumMotorB = pwm_gpio_to_slice_num(PIN_PWM_ENABLEB);
    // Set period for frequency divisor
    pwm_set_clkdiv_int_frac(sliceNumMotorB, PWM_DIV_INTEGER, PWM_DIV_FRAC); // What frequency enters to the PWM?
    // Set top (wrap) value (Determines the frequency)
    pwm_set_wrap(sliceNumMotorB, PWM_TOP_VALUE);
    // Set zero duty
    pwm_set_chan_level(sliceNumMotorB, PWM_CHA, PWM_DUTY_ZERO);
    // Enable PWM
    pwm_set_enabled(sliceNumMotorB, true); 

    //Inicia en el estado de Reset
    Flags.WORD = 1;

    Move();
    while (1)
    {
        if(!gpio_get(1) && !gpio_get(0)){
            printf("Va derecho.........\n");
            pwm_set_chan_level(sliceNumMotorB, PWM_CHA, PWM_DUTY_ZERO);
            pwm_set_chan_level(sliceNumMotorA, PWM_CHA, PWM_DUTY_ZERO);
        }

        else if (band_right)
        {    
            printf("Corrige derecha................. \n");
            pwm_set_chan_level(sliceNumMotorA, PWM_CHA, pwm_level_right);
            pwm_set_chan_level(sliceNumMotorB, PWM_CHA, pwm_level);
            band_right = false;
        }
        else if (band_left)
        {
            printf("Corrige izquierda................. \n");
            pwm_set_chan_level(sliceNumMotorB, PWM_CHA, pwm_level_left);
            pwm_set_chan_level(sliceNumMotorA, PWM_CHA, pwm_level);
            band_left = false;
        }
        
        __wfi();     
        //sleep_ms(1000);
    }
    
    while (true)
    {
        switch (Flags.WORD)
        {
        case 1:
            Reset();
            uart_puts(UART_ID, str);
            break;
        case 12:
            //Pasar a .h
            pwm_init(slice_num, &cfg1, false);
            //CONFIGURACIÓN ALARMA 10MS
            gpio_set_function(MEASURE_PIN, GPIO_FUNC_PWM);
            now = get_absolute_time();
            target = delayed_by_ms(now, COUNT_MEASURE_TIME);
            hardware_alarm_set_target(alarm1, target);
            slice_num = pwm_gpio_to_slice_num(MEASURE_PIN);
            pwm_set_enabled(slice_num, true);
            break;
        case 0x10:
            Fin_Trama();
            Triangulación();
            Move();           
            break;
        default:
            break;
        }
        if(!Flags.BITS.Reset){
         __wfi();
        }
    }
#endif
}

/// ---------------- Funciones ---------------- ///
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

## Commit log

2024-11-19 Se agrega Cronograma de actividades y los diagramas de flujo tentativos del desarrollo del proyecto
    [Cronograma_ProyectoFinal_ ED3.xlsx]
2024-11-19 Se agrega la libreria para el uso y control de la pantalla OLED escrita por Larry Bank (bitbank@pobox.com), extraida de https://wokwi.com/projects/393154286020492289
2024-11-19 Update README.md
    Actualización de las descripción del proyecto
2024-11-19 Update README.md
    Actualización del README con la descripción del proyecto
2024-11-20 Ejemplo Uart-DMA
    Prueba de comunicación mediante UART y traspaso a través del DMA
2024-12-01 Configuración de la comunicación mediante el UART y estimación de la potencia de las balizas a través del PWM. Además de desarrollar la función que se encarga de la triangulación.
2024-12-01 Se actualiza el cronograma con las actividades realizadas durante la semana
    [Cronograma_ProyectoFinal_ ED3.xlsx]
2024-12-06 Ajustes en la triangulación y configuración de los GPIOs para la salidas de los motores
2024-12-06 Integración de animaciones, menus, y demás aspectos para ser mostrados en la pantalla
2024-12-07 Se añaden los diseños de PCBs a usar
    [Sp_OLED_BUTTOMS.brd, Sp_OLED_BUTTOMS.sch, Sp_pico.brd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]
2024-12-08 Unión del menú con la triangulación y desarrollo del seguidor de línea
2024-12-12 Unificación del menú, con la comunicación bluetooth, y ajustes en la triangulación y el seguidor de línea
2024-12-12 Pruebas en el control de motores
2024-12-13 Eliminación de funciones innecesarias, se agregan comentarios al código y se ajustan los umbrales
